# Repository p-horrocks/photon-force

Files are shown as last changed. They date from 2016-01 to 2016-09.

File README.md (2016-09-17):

# photon-force

A laser tag implementation using the Particle Photon as the main processor.

# Compiling

To compile this project locally you'll need the gcc-arm toolchain as well as the
Photon firmware. It's built against firmware 0.4.9

* If you get permission problems running npm, see here:
https://docs.npmjs.com/getting-started/fixing-npm-permissions

(On Debian)
> apt-get install gcc-arm-none-eabi dfu_util npm
> npm install -g particle-cli
> git clone https://github.com/spark/firmware.git
> cd firmware
> git checkout release/v0.4.9

Next, create a symlink in firmware/user/applications to where this source is
checked out.

# Flashing

Plug the Photon into a USB port. Once it has powered up, hold down the setup
button then tap the reset button. The status LED will flash magenta for a few
seconds then flash yellow, release the setup button. With the LED flashing
yellow run 'make install' and the firmware will be uploaded using dfu.

# Qt Creator

These files are the Qt Creator project files, they're not needed to compile
the project, they just make is easier to use Qt Creator as the IDE:

  photon-force.config
  photon-force.creator
  photon-force.files
  photon-force.includes

# Gerber generation

From within PCBNew:
- File->Plot
- Plot format: Gerber
- Check Layers
    F.Cu
    B.Cu
    F.SilkS
    B.SilkS
    F.Mask
    B.Mask
    Edge.Cuts
- Check Options
    Plot module value on silkscreen
    Plot module reference on silkscreen
    Plot other module texts on silkscreen
    Exclude PCB edge layer from other layers
    Default line width 0.15mm
- Check Gerber Options
    Use proper filename extensions
- Click 'Plot'
- Click 'Generate Drill File'
- Check Drill Units: Inches
- Check Zeros Format: Decimal format
- Check Drill Map File Format: Gerber
- Check Options: Minimal header
- Check Drill Origin: Absolute
- Click 'Drill File'
- Remove layer names from plot files (so they're all <name>.gXX)
- Rename *.gbr to *.gml
- Rename *.drl to *.txt
- zip with zip -r <zip file> <name>.*
- zip file ready for upload!

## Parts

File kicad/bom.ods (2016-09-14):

Suits | 2
AUD to USD | 1.35
Overstock ratio | 1
Part | Manufacturer | Supplier | Supplier Ref | Description | Prototype | SensorPod # | CommandPod # | Required | MOQ | Unit cost | Order | Marginal | Total
MC0805B221K500CT | Multicomp | E14 | 175920803 | Capacitor – 220pF | 0 | 0 | 1 | 2 | 10 | $0.02 | 10 | $0.02 | $0.24
MC0805B104K500CT | Multicomp | E14 | 1759265 | Capacitor – 0.1µF | 0 | 12 | 0 | 96 | 150 | $0.02 | 150 | $0.96 | $3.00
MC0805B105K160CT | Multicomp | E14 | 232085303 | Capacitor – 1µF | 0 | 5 | 7 | 54 | 100 | $0.05 | 100 | $1.38 | $5.10
MC0805B225K250CT | Multicomp | E14 | 232082903 | Capacitor – 2.2µF | 0 | 0 | 1 | 2 | 10 | $0.20 | 10 | $0.20 | $1.96
MC0805B475K160CT | Multicomp | E14 | 232085403 | Capacitor – 4.7µF | 0 | 0 | 3 | 6 | 10 | $0.23 | 10 | $0.68 | $2.27
TSOP38438 | Vishay | E14 | 2251364 | IR receiver | 0 | 0 | 0 | 0 | 1 | $1.65 | 0 | $0.00 | $0.00
 |  |  |  | - price break | 0 | 4 | 0 | 32 | 50 | $1.27 | 50 | $20.32 | $63.50
WS2812B | WorldSemi | Aliexpress |  | RGB LED | 0 | 12 | 0 | 96 | 1000 | $0.13 | 1000 | $6.05 | $126.00
SPC20494 |  | E14 | 1258962 | 8-way header | 0 | 0 | 0 | 0 | 1 | $0.38 | 0 | $0.00 | $0.00
 |  |  |  | - price break | 0 | 0 | 0 | 0 | 25 | $0.34 | 0 | $0.00 | $0.00
SPC20504 | Multicomp | E14 | 1221738 | 40-way header (2 row) | 0 | 0.1 | 0.5 | 2 | 1 | $1.11 | 2 | $1.00 | $2.22
MC01W08051160R | Multicomp | E14 | 9332650 | Resistor – 160R | 0 | 4 | 0 | 32 | 100 | $0.03 | 100 | $0.43 | $2.70
MCHP05W4F6800T5E | Multicomp | E14 | 157645603 | Resistor – 680R | 0 | 0 | 2 | 4 | 50 | $0.03 | 50 | $0.05 | $1.30
MC0805S8F1002T5E | Multicomp | E14 | 1632457 | Resistor – 10K | 0 | 4 | 6 | 44 | 1 | $0.00 | 44 | $0.09 | $0.18
MC01W0805551K | Multicomp | E14 | 933465303 | Resistor – 51K | 0 | 0 | 1 | 2 | 50 | $0.02 | 50 | $0.02 | $1.05
SN74HC165D | Texas Instruments | E14 | 9591192 | Shift register | 0 | 1 | 0 | 8 | 10 | $0.87 | 10 | $3.49 | $8.72
479-0140-0 | Deltron | E14 | 2393865 | Sensor Enclosure | 0 | 1 | 0 | 8 | 10 | $3.42 | 10 | $13.68 | $34.20
1583E |  | E14 | 1242873 | Cable | 0 | 0.5 | 1 | 6 | 1 | $1.13 | 6 | $3.39 | $6.78
14.53.051 |  | E14 | 2494620 | Strain relief | 0 | 1 | 5 | 18 | 10 | $0.58 | 20 | $5.22 | $11.60
T812108A101CEU |  | E14 | 221524601 | 8-way connector | 0 | 1 | 5 | 18 | 1 | $0.49 | 18 | $4.41 | $8.82
IRFML8244TRPBF |  | E14 | 2128370 | N-MOSFET | 0 | 0 | 4 | 8 | 20 | $0.22 | 20 | $0.86 | $4.30
Photon | Particle | Seeed | 114990286 | Brain | 0 | 0 | 1 | 2 | 1 | $25.63 | 2 | $25.63 | $51.26
Mini vibration motor 2.7mm |  | Seeed | 316040004 | Vibration motor | 0 | 0 | 1 | 2 | 1 | $1.62 | 2 | $1.62 | $3.24
 |  | Seeed |  | Sensorpod PCB | 0 | 1 | 0 | 8 | 10 | $2.33 | 10 | $9.32 | $23.30
MCWIW1028-F-104-LF |  | E14 | 1609938 | Trimpot – 100K | 0 | 0 | 2 | 4 | 1 | $0.65 | 4 | $1.29 | $2.58
MCSDRH125B-100MHF |  | E14 | 186445103 | Inductor – 10µH | 0 | 0 | 1 | 2 | 5 | $0.68 | 5 | $0.68 | $3.42
MCBF7330-330MU |  | E14 | 186428103 | Inductor – 33µH | 0 | 0 | 2 | 4 | 5 | $0.47 | 5 | $0.93 | $2.34
ABS-205-RC |  | E14 | 167554703 | Speaker | 0 | 0 | 1 | 2 | 1 | $2.77 | 2 | $2.77 | $5.54
 |  | K-Mart |  | Gun shell | 0 | 0 | 1 | 2 | 1 | $9.00 | 2 | $9.00 | $18.00
LM2731XMF |  | E14 | 8181640 | Boost controller | 0 | 0 | 1 | 2 | 1 | $2.88 | 2 | $2.88 | $5.76
TPA2005D1DGN | Texas Instruments | E14 | 2075395 | Amplifier | 1 | 0 | 1 | 2 | 1 | $2.31 | 3 | $2.31 | $6.93
2200mAh LiPo |  | Seeed |  | Battery | 0 | 0 | 1 | 2 | 1 | $5.98 | 2 | $5.98 | $11.96
 |  | E14 |  | Schottky diode | 0 | 0 | 1 | 2 |  |  | 0 | $0.00 | $0.00
B2B-PH-K-S(LF)(SN) | JST | E14 | 9491856 | Battery header | 0 | 0 | 1 | 2 | 10 | $0.24 | 10 | $0.24 | $2.39
47642-0001 | Molex | E14 | 2396171 | Micro USB socket | 0 | 0 | 1 | 2 | 1 | $1.12 | 2 | $1.12 | $2.24
MCBBJ65 | Multicomp | E14 | 2396146 | Jumper wire assortment | 1 | 0 | 0 | 0 | 1 | $5.11 | 1 | $0.00 | $5.11
MCBB400 | Multicomp | E14 | 2395961 | Breadboard | 2 | 0 | 0 | 0 | 1 | $4.44 | 2 | $0.00 | $8.88
5-826936-0 | TE Connectivity | E14 | 1822162 | 50 pin header | 1 | 0 | 0 | 0 | 1 | $3.20 | 1 | $0.00 | $3.20
 |  |  |  |  |  |  |  |  |  |  |  | $126.02 | $440.08
 |  |  |  |  |  |  |  |  |  |  | = items ordered
1591XXLTBU | Hammond | E14 | 1511173 | Sensor Enclosure
1591XXMTBU | Hammond | Digikey | 1591XXMTBU-ND | Sensor Enclosure
C9 (TRGY) | Serpac |  |  | Sensor Enclosure
 | Serpac |  |  | Command Enclosure
 |  | Hobbyking | T2200.1S.20 | Battery

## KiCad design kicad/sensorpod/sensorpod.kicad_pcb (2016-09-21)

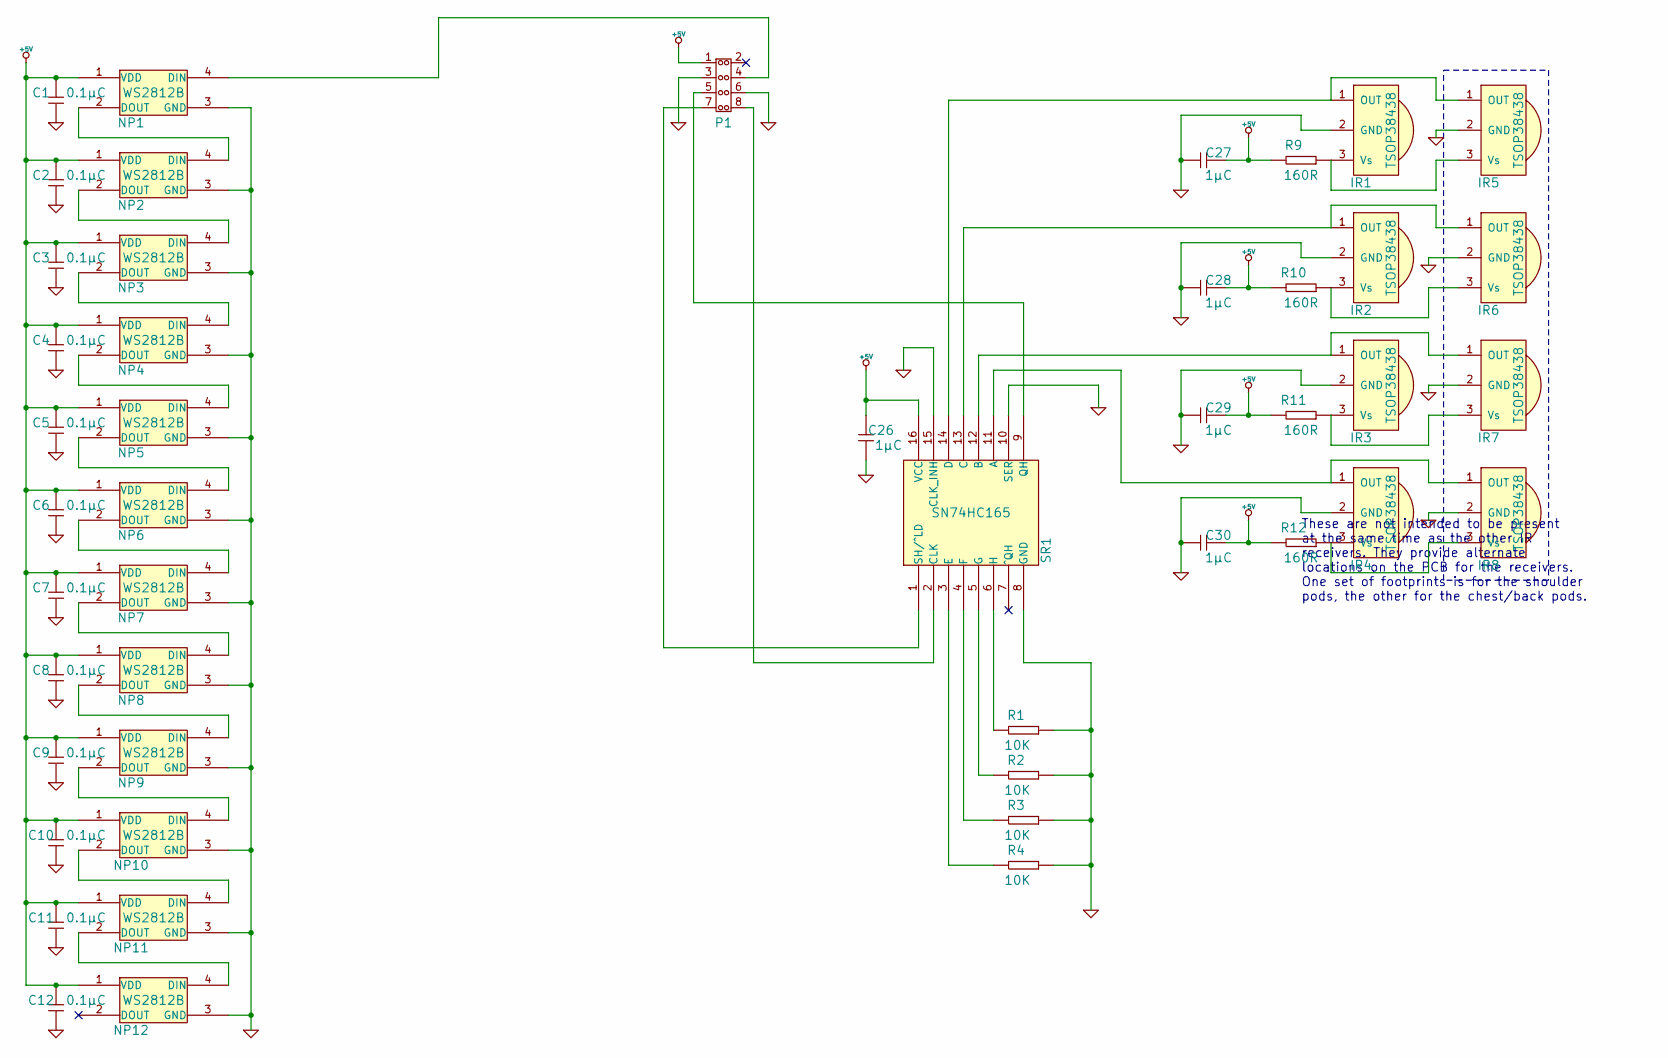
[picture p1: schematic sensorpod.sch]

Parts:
C1, C2, C3, C4, C5, C6, C7, C8, C9, C10, C11, C12, C26, C27, C28, C29, C30: GENERIC_CAPACITOR; 0805
IR1, IR2, IR3, IR4, IR5, IR6, IR7, IR8: TSOP38438; Minicast
NP1, NP2, NP3, NP4, NP5, NP6, NP7, NP8, NP9, NP10, NP11, NP12: WS2812B; 5050
P1: HEADER_(8_WAY); Header_4x2
R1, R2, R3, R4, R9, R10, R11, R12: GENERIC_RESISTOR; 0805
SR1: SN74HC165; SOIC-16

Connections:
+5V: C1.1, C2.1, C3.1, C4.1, C5.1, C6.1, C7.1, C8.1, C9.1, C10.1, C11.1, C12.1, C26.1, C27.1, C28.1, C29.1, C30.1, NP1.1 (VDD), NP2.1 (VDD), NP3.1 (VDD), NP4.1 (VDD), NP5.1 (VDD), NP6.1 (VDD), NP7.1 (VDD), NP8.1 (VDD), NP9.1 (VDD), NP10.1 (VDD), NP11.1 (VDD), NP12.1 (VDD), P1.1, R9.1, R10.1, R11.1, R12.1, SR1.16 (VCC)
GND: C1.2, C2.2, C3.2, C4.2, C5.2, C6.2, C7.2, C8.2, C9.2, C10.2, C11.2, C12.2, C26.2, C27.2, C28.2, C29.2, C30.2, IR1.2 (GND), IR2.2 (GND), IR3.2 (GND), IR4.2 (GND), IR5.2 (GND), IR6.2 (GND), IR7.2 (GND), IR8.2 (GND), NP1.3 (GND), NP2.3 (GND), NP3.3 (GND), NP4.3 (GND), NP5.3 (GND), NP6.3 (GND), NP7.3 (GND), NP8.3 (GND), NP9.3 (GND), NP10.3 (GND), NP11.3 (GND), NP12.3 (GND), P1.3, P1.6, R1.2, R2.2, R3.2, R4.2, SR1.8 (GND), SR1.10 (SER), SR1.15 (CLK_INH)
unnamed: P1.8, SR1.2 (CLK)
unnamed: P1.7, SR1.1 (SH/^LD)
unnamed: NP11.2 (DOUT), NP12.4 (DIN)
unnamed: NP10.2 (DOUT), NP11.4 (DIN)
unnamed: IR2.3 (Vs), IR6.3 (Vs), R10.2
unnamed: IR1.1 (OUT), IR5.1 (OUT), SR1.14 (D)
unnamed: IR4.3 (Vs), IR8.3 (Vs), R12.2
unnamed: IR3.3 (Vs), IR7.3 (Vs), R11.2
unnamed: IR1.3 (Vs), IR5.3 (Vs), R9.2
unnamed: IR4.1 (OUT), IR8.1 (OUT), SR1.11 (A)
unnamed: IR3.1 (OUT), IR7.1 (OUT), SR1.12 (B)
unnamed: IR2.1 (OUT), IR6.1 (OUT), SR1.13 (C)
unnamed: NP1.4 (DIN), P1.4
unnamed: R4.1, SR1.3 (E)
unnamed: R3.1, SR1.4 (F)
unnamed: R2.1, SR1.5 (G)
unnamed: R1.1, SR1.6 (H)
unnamed: P1.5, SR1.9 (QH)
unnamed: NP9.2 (DOUT), NP10.4 (DIN)
unnamed: NP5.2 (DOUT), NP6.4 (DIN)
unnamed: NP4.2 (DOUT), NP5.4 (DIN)
unnamed: NP3.2 (DOUT), NP4.4 (DIN)
unnamed: NP2.2 (DOUT), NP3.4 (DIN)
unnamed: NP1.2 (DOUT), NP2.4 (DIN)
unnamed: NP8.2 (DOUT), NP9.4 (DIN)
unnamed: NP7.2 (DOUT), NP8.4 (DIN)
unnamed: NP6.2 (DOUT), NP7.4 (DIN)

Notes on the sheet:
These are not intended to be present at the same time as the other IR receivers. They provide alternate locations on the PCB for the receivers. One set of footprints is for the shoulder pods, the other for the chest/back pods.

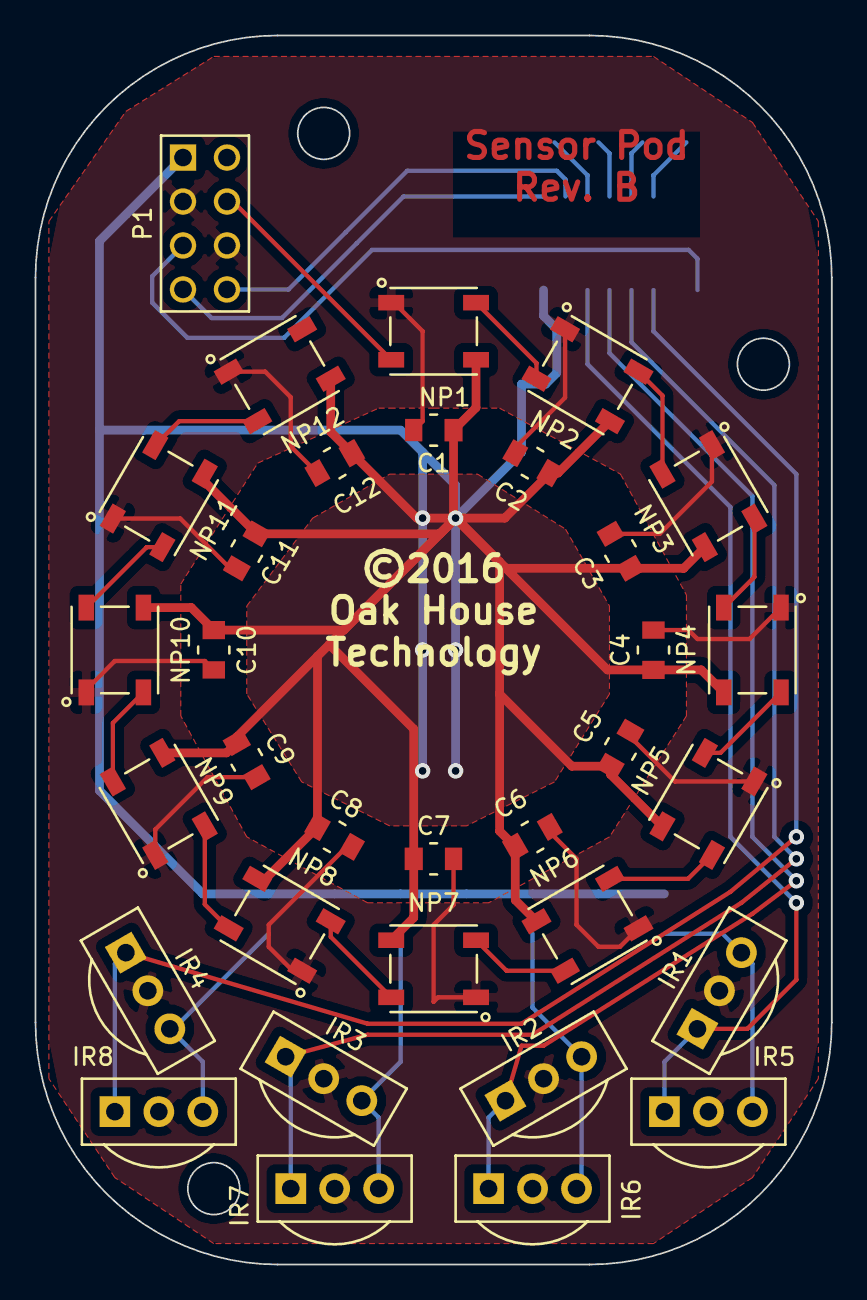
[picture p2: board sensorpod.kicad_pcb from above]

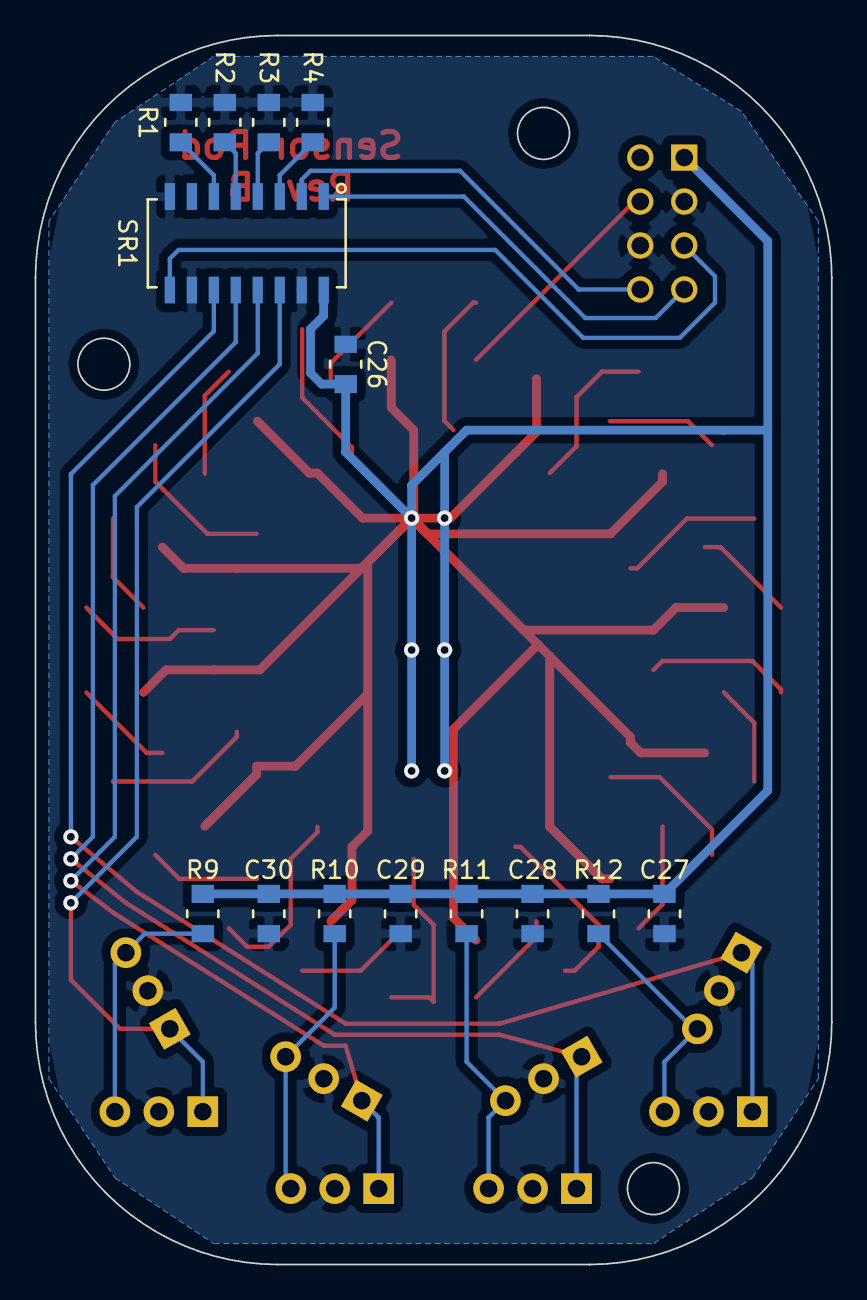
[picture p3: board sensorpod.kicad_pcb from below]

Board: 2 copper layers, 46.0 x 71.0 mm, 47 parts (14 on the bottom side), 29 nets.

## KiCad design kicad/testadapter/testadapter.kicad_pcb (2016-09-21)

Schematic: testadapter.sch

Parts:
P1: HEADER_5X2; Header_5x2
P2, P3, P4, P5: HEADER_(8_WAY); Header_4x2
Q1, Q2, Q3: IRFML8244TRPBF; SOT-23; Part # IRFML8244TRPBF
R1, R2, R3: GENERIC_RESISTOR; 0805

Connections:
+3.3V: P1.2, Q1.1 (G), Q2.1 (G), Q3.1 (G)
+5V: P1.1, P2.1, P3.1, P4.1, P5.1, R1.2, R2.2, R3.2
Clock: P2.8, P3.8, P4.8, P5.8, Q3.3 (D), R3.1
GND: P1.3, P2.3, P2.6, P3.3, P3.6, P4.3, P4.6, P5.3, P5.6
Load: P2.7, P3.7, P4.7, P5.7, Q2.3 (D), R2.1
unnamed: P1.5, Q2.2 (S)
unnamed: P1.4, Q1.2 (S)
unnamed: P1.6, Q3.2 (S)
unnamed: P1.8, P3.5
unnamed: P1.7, P2.5
unnamed: P1.9, P4.5
unnamed: P1.10, P5.5
NeoPixels: P2.4, P3.4, P4.4, P5.4, Q1.3 (D), R1.1

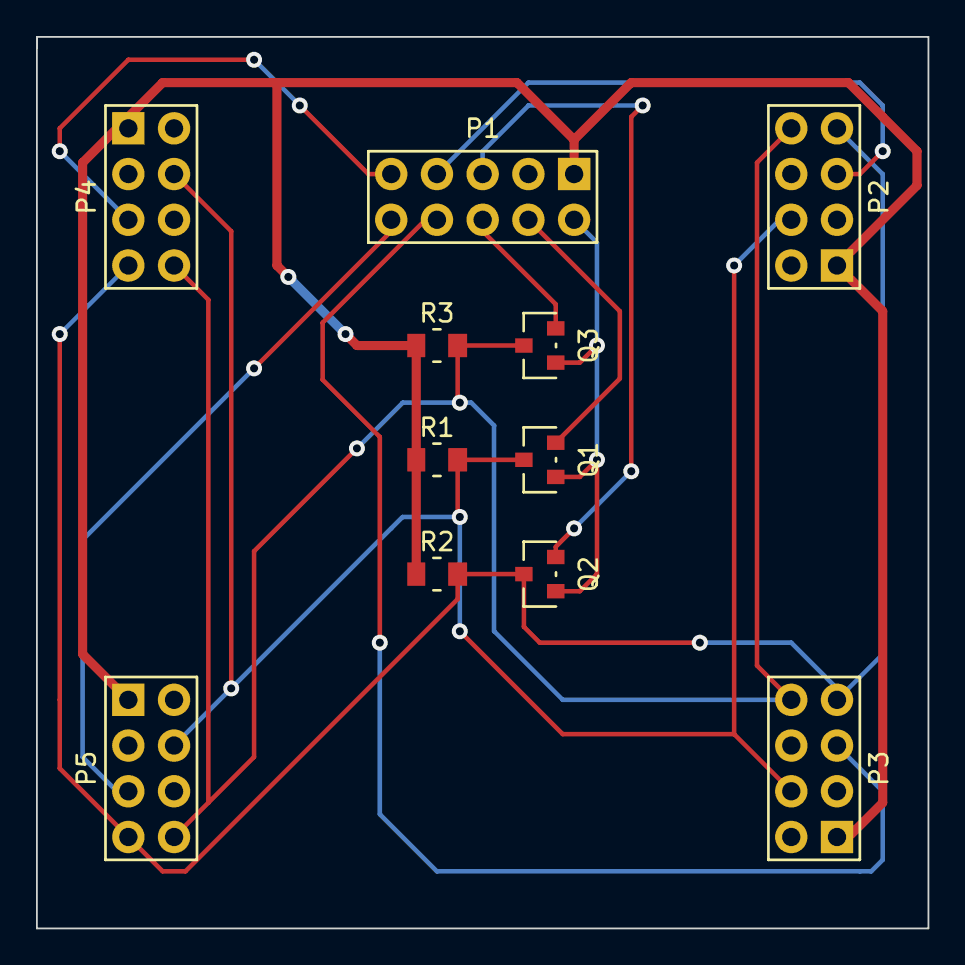
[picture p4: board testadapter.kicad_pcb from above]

Board: 2 copper layers, 49.5 x 49.5 mm, 11 parts (0 on the bottom side), 13 nets.

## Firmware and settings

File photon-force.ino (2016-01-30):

#include "application.h"

#include "audio.h"
#include "audio_data.h"
#include "dma.h"
#include "iremitter.h"
#include "irreader.h"
#include "neopix.h"
#include "serialstream.h"
#include "settings.h"
#include "trigger.h"

#define VERSION "0.1"

SYSTEM_MODE(MANUAL);

// Photon pin assignments
// ----------------------
//
// Because there are so many dependent functions they can't all be defined here
// easily. This table shows the assignments, however, and hopefully they stay
// relatively in-sync with reality.
//
// Function         Requires  Pin     TIM DMA1
// ------------------------------------------
//                            D0/PB7
// IR send          timer/DMA D1/PB6  4.1 0.2
// Trigger          interrupt D2/PB5
// NeoPixel circle  timer/DMA D3/PB4  3.1 4.5
// IR recv (enable) -         D4/PB3
// IR recv (clk)    -         D5/PA15
// Haptic           -         D6/PA14
//                            D7/PA13
//
// Power (sense)    ADC       A0/PC5
// IR recv (input1) 5V        A1/PC3
// IR recv (input2) 5V        A2/PC2
// Power (enable)   -         A3/PA5
// IR recv (input3) 5V        A4/PA6
// IR recv (input4) 5V        A5/PA7
// Audio            DAC/DMA   DAC/PA4 7   5.7
//                            WKP/PA0

// Note: interrupt not available on D0

void setup()
{
    // serialstream must be initialised first.
    serialstream::init();
    neopix::init();
    irreader::init();
    iremitter::init();
    trigger::init();
    audio::init();

    serialstream::print("*** PhotonForce " VERSION " ***\r\n");
}

void loop()
{
    uint32_t now = micros();

    serialstream::update();
    neopix::update(now);
    irreader::update(now);

    if(trigger::shouldFire(now))
    {
        serialstream::print("Firing\r\n");

        iremitter::sendCode(settings::ourIrCode());
        audio::play();
    }
}

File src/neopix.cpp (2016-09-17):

#include "application.h"

#include "dma.h"
#include "hitpoints.h"
#include "neopix.h"
#include "settings.h"

// Each pixel requires a value per bit per colour component. One extra
// to reset the output value when finished.
#define NEOPIX_COUNT 12
#define BUF_ELEMENTS ((NEOPIX_COUNT * 3 * 8) + 1)

extern "C" void neopix_dmaComplete()
{
    if(DMA_GetITStatus(DMA1_Stream4, DMA_IT_TCIF4))
    {
        DMA_ClearITPendingBit(DMA1_Stream4, DMA_IT_TCIF4);
        DMA_Cmd(DMA1_Stream4, DISABLE);
        TIM_Cmd(TIM3, DISABLE);
    }
}

namespace neopix
{

namespace
{

uint32_t _lastUpdate               = 0;
uint16_t _pwmBuffer[BUF_ELEMENTS]  = { 0 };
//uint8_t _fadeFactors[NEOPIX_COUNT] = { 0, 0, 0, 0, 0, 0, 0, 0, 0, 0, 0, 0, 0, 0, 0, 0, 1, 3, 6, 12, 36, 70, 135, 255 };
uint8_t _fadeFactors[NEOPIX_COUNT] = { 0, 0, 0, 0, 1, 3, 6, 12, 36, 70, 135, 255 };
uint8_t _currentPix                = 0;

// Calcuate a colour channel value given the base value and the stage (used to
// determine the amount of fade to apply).
uint8_t pixComponentValue(uint8_t base, int stage)
{
    uint32_t v = _fadeFactors[stage];
    v *= base;
    return (uint8_t)(v >> 8);
}

// Converts a sinle colour channel value to its PWM representation and appends
// it to the PWM buffer ready for transmission to the hardware.
void appendToPwm(uint8_t value, int& pos)
{
    if(pos >= BUF_ELEMENTS)
        return;

    for(int i = 0; i < 8; ++i)
    {
        if(value & 0x80)
        {
            _pwmBuffer[pos++] = 16;
        }
        else
        {
            _pwmBuffer[pos++] = 8;
        }
        value <<= 1;
    }
}

void createColourCyclePwm(uint8_t r, uint8_t g, uint8_t b)
{
    int pos = 0;
    for(int i = 0; i < NEOPIX_COUNT; ++i)
    {
        int pix = i + _currentPix;
        if(pix >= NEOPIX_COUNT)
        {
            pix -= NEOPIX_COUNT;
        }

        const uint8_t red   = pixComponentValue(r, pix);
        const uint8_t green = pixComponentValue(g, pix);
        const uint8_t blue  = pixComponentValue(b, pix);

        appendToPwm(green, pos);
        appendToPwm(red,   pos);
        appendToPwm(blue,  pos);
    }
}

void createRingPulsePwm(uint8_t r, uint8_t g, uint8_t b)
{
    const uint8_t red   = pixComponentValue(r, _currentPix);
    const uint8_t green = pixComponentValue(g, _currentPix);
    const uint8_t blue  = pixComponentValue(b, _currentPix);

    int pos = 0;
    for(int i = 0; i < NEOPIX_COUNT; ++i)
    {
        appendToPwm(green, pos);
        appendToPwm(red,   pos);
        appendToPwm(blue,  pos);
    }
}

} // namespace

void init()
{
    // The firmware PWM implementation can't be used because it only uses a
    // 500Hz signal. The NeoPixels use a 800kHz signal.
    RCC_AHB1PeriphClockCmd(RCC_AHB1Periph_GPIOB, ENABLE);
    RCC_AHB1PeriphClockCmd(RCC_AHB1Periph_DMA1, ENABLE);
    RCC_APB1PeriphClockCmd(RCC_APB1Periph_TIM3, ENABLE);

    GPIO_InitTypeDef gpioInit = { 0 };
    gpioInit.GPIO_Pin   = GPIO_Pin_4;
    gpioInit.GPIO_Mode  = GPIO_Mode_AF;
    gpioInit.GPIO_OType = GPIO_OType_PP;
    gpioInit.GPIO_Speed = GPIO_Speed_100MHz;
    gpioInit.GPIO_PuPd  = GPIO_PuPd_NOPULL;
    GPIO_Init(GPIOB, &gpioInit);
    GPIO_PinAFConfig(GPIOB, GPIO_PinSource4, GPIO_AF_TIM3);

    // Choose a prescaler value to give a 20MHz PWM. With a period of 25 that
    // gives a PWM frequency of 800kHz. A 0.4us pulse (to signify a 0) will be 8
    // ticks while a 0.8us pulse (for a 1) will be 16 ticks.
    const uint32_t frequency = 800000 * 25;
    const uint32_t timClock  = SystemCoreClock / 2; // TIM3 runs at half the system frequency.

    // Timer configuration.
    TIM_TimeBaseInitTypeDef timInit = { 0 };
    timInit.TIM_Period        = 25;
    timInit.TIM_Prescaler     = (timClock / frequency) - 1;
    timInit.TIM_ClockDivision = 0;
    timInit.TIM_CounterMode   = TIM_CounterMode_Up;
    TIM_DeInit(TIM3);
    TIM_TimeBaseInit(TIM3, &timInit);

    // Timer output channel configuration.
    TIM_OCInitTypeDef ocInit = { 0 };
    ocInit.TIM_OCMode        = TIM_OCMode_PWM1;
    ocInit.TIM_OutputState   = TIM_OutputState_Enable;
    ocInit.TIM_Pulse         = 0;
    ocInit.TIM_OCPolarity    = TIM_OCPolarity_High;
    ocInit.TIM_OCIdleState   = TIM_OCIdleState_Reset;
    TIM_OC1Init(TIM3, &ocInit);

    // Configure DMA1 channel 1 to copy to the PWM output.
    DMA_InitTypeDef dmaInit;
    DMA_StructInit(&dmaInit);
    dmaInit.DMA_Channel            = DMA_Channel_5;
    dmaInit.DMA_PeripheralBaseAddr = (uint32_t)&TIM3->CCR1;
    dmaInit.DMA_Memory0BaseAddr    = (uint32_t)&_pwmBuffer;
    dmaInit.DMA_DIR                = DMA_DIR_MemoryToPeripheral;
    dmaInit.DMA_BufferSize         = BUF_ELEMENTS;
    dmaInit.DMA_PeripheralInc      = DMA_PeripheralInc_Disable;
    dmaInit.DMA_MemoryInc          = DMA_MemoryInc_Enable;
    dmaInit.DMA_PeripheralDataSize = DMA_PeripheralDataSize_HalfWord;
    dmaInit.DMA_MemoryDataSize     = DMA_MemoryDataSize_HalfWord;
    dmaInit.DMA_Mode               = DMA_Mode_Normal; // ie: not circular
    dmaInit.DMA_Priority           = DMA_Priority_High;
    dmaInit.DMA_FIFOMode           = DMA_FIFOMode_Enable;
    dmaInit.DMA_FIFOThreshold      = DMA_FIFOThreshold_HalfFull;
    dmaInit.DMA_MemoryBurst        = DMA_MemoryBurst_INC4;
    dmaInit.DMA_PeripheralBurst    = DMA_PeripheralBurst_Single;
    DMA_DeInit(DMA1_Stream4);
    DMA_Init(DMA1_Stream4, &dmaInit);
    DMA_ITConfig(DMA1_Stream4, DMA_IT_TC, ENABLE);

    TIM_OC1PreloadConfig(TIM3, TIM_OCPreload_Enable);
    TIM_ARRPreloadConfig(TIM3, ENABLE);
    TIM_DMAConfig(TIM3, TIM_DMABase_CCR1, TIM_DMABurstLength_1Transfer);
    TIM_SelectCCDMA(TIM3, ENABLE);
    TIM_DMACmd(TIM3, TIM_DMA_CC1, ENABLE);

    NVIC_InitTypeDef nvicInit                  = { 0 };
    nvicInit.NVIC_IRQChannel                   = DMA1_Stream4_IRQn;
    nvicInit.NVIC_IRQChannelPreemptionPriority = 4;
    nvicInit.NVIC_IRQChannelSubPriority        = 0;
    nvicInit.NVIC_IRQChannelCmd                = ENABLE;
    NVIC_Init(&nvicInit);

    // Put out handler into the interrupt vector table
    uint32_t* interruptTable = (uint32_t*)SCB->VTOR;
    interruptTable[dma::IrqDMA1_Stream4] = (uint32_t)&neopix_dmaComplete;

    _lastUpdate = micros();
}
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

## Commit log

2016-01-26 Started utility namespace for DMA stuff
2016-01-26 Allow for different DMA streams
2016-01-26 Use DMA to transfer data to NeoPixels. Main loop runs as fast as possible
2016-01-28 Added number printing
2016-01-30 Use interrupt to handle DMA completion
2016-01-30 Added 600rpm fire rate
2016-01-30 LED colour specified in settings
2016-02-06 Added IR sending. Lots of debugging still included since it doesn't work yet
    [iremitter.cpp]
2016-02-13 Starting on schematic
    [photon-force.sch]
2016-02-13 NeoPixel string in the schematic
    [gun.sch, photon-force.sch, sensorpod.sch]
2016-02-16 Sensor pos schematic done
    [gun.sch, photon-force.sch, sensorpod.sch]
2016-02-18 Split command pod and sensor pod into separate kicad projects
    They'll end up being separate PCBs, so separate projects makes sense
    [commandpod.sch, gun.sch, sensorpod.sch]
2016-02-18 Started putting in footprints for sensorpod
    [sensorpod.sch]
2016-02-18 Fixed up use of common parts library
    [commandpod.sch]
2016-02-18 Added footprints for sensorpod
    [sensorpod.kicad_pcb]
2016-02-20 Sensor pod footprints all in
    [sensorpod.kicad_pcb, sensorpod.sch]
2016-02-22 Initial sensor pod PCB
    [sensorpod.kicad_pcb]
2016-02-22 Reduced component count so it will fit
    [sensorpod.kicad_pcb, sensorpod.sch]
2016-02-23 Swap a few cable pins
    [sensorpod.kicad_pcb, sensorpod.sch]
2016-02-23 Prototype sensor pod PCB complete
    [sensorpod.kicad_pcb]
2016-02-26 Updated sensorpod schematic and PCB to fit into Serpac C9 enclosure
    [sensorpod.kicad_pcb, sensorpod.sch]
2016-02-29 Remove vibration motor from sensor pos - it will just be in the command pod
    [sensorpod.kicad_pcb, sensorpod.sch]
2016-03-01 Updated pin assignments to allow for i2c haptic controller
2016-03-02 Added SPDT switch, put in ir emitter with power switch
    [commandpod.sch]
2016-03-02 Moved shift register to allow more room for cable entry
    [sensorpod.kicad_pcb]
2016-03-02 More work on command pod
    [commandpod.sch]
2016-03-03 Added heirarchial schematics for command pod
    [Audio.sch, GunIface.sch, Haptic.sch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]
2016-03-03 Annotated schematics
    [Audio.sch, GunIface.sch, Haptic.sch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]
2016-03-03 Can't remember
    [Audio.sch, bom.ods]
2016-03-04 Updated BOM
    [bom.ods]
2016-03-07 Put in charging circuit
    [Audio.sch, GunIface.sch, Haptic.sch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]
2016-03-07 More stuff
    [bom.ods, sensorpod.kicad_pcb, sensorpod.sch]
2016-03-13 Updated prices with actual purchase price
    [bom.ods]
2016-03-13 Added github standard kicad gitignore
2016-03-20 Updated neopixel supply
    [bom.ods]
2016-07-12 Minor tweaks
    [bom.ods, sensorpod.kicad_pcb]
2016-07-19 Created script to simplify the generation of PCB manufacturing package
2016-07-19 Added extra vias to central 5V fill
    [sensorpod.kicad_pcb]
2016-07-20 Update BOM
    [bom.ods]
2016-09-20 Corrected wrong pad assignment on ir receiver footprint
    [sensorpod.kicad_pcb, sensorpod.sch]
2016-09-20 Added start of adapter for testing
    [testadapter.sch]
2016-09-21 Created adapter PCB for testing sensorpods
    [testadapter.kicad_pcb, testadapter.sch]
2016-09-21 Put in alternate IR receiver locations on sensor pod
    Should make things easier when the pins need to be bent to lie them
    flat on the chest/back pods
    [sensorpod.kicad_pcb, sensorpod.sch]

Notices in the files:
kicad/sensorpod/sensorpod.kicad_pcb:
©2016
